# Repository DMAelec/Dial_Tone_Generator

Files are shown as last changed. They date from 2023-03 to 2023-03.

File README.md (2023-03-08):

# DIAL TONE GENERATOR

 This circuit provides a 1 volt peak-to-peak dial tone signal with equal proportions of 350Hz and 440Hz sine waves. The two frequencies are generated in multivibrator sections U1A and U1B. Triangle-like waveforms from the multivibrator sections are fed to summing amplifier U1D. A 470pF capacitor in the feedback path of U1D removes some of the unwanted harmonics from the composite waveform, which is then fed to section U1C, a Sallen-Key low-pass filter. U1C further reduces the harmonics, providing a high-quality summed-sine signal at its output. The two frequencies are close enough to permit a single-filter design, with the summing resistors at U1D's input selected to emphasize the 440Hz component, accordingly.

Calibration is performed by connecting a frequency counter to the "350 TP" and "440 TP" test points, and adjusting the respective trimmer potentiometers to obtain the correct frequencies. The frequencies are relatively independent of power supply voltage, and the single +7.5v power supply may be derived from a simple regulator circuit. The circuit consumes less than 3 milliamperes of current.

For convenience and economy, the circuit was designed with one CMOS quad op-amp integrated circuit.

BASED ON SCHEMATIC FROM:
https://www.theremin.us/Circuit_Library/dial_tone_generator.html

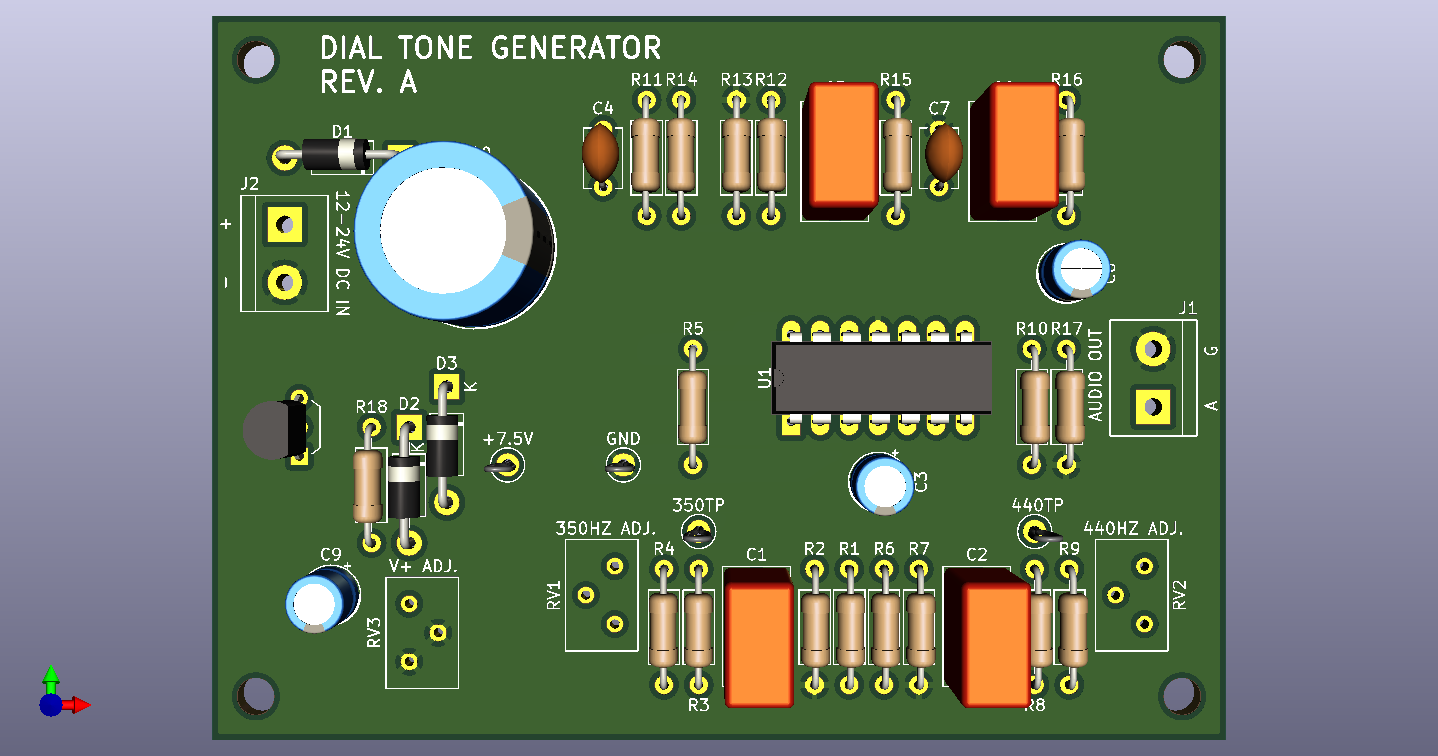
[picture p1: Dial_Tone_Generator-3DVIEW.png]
3DVIEW


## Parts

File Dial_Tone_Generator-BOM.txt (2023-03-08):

REFRENCE		|		DESCRIPTION		|		PART NUMBER
-------------------------------------------------------------------------------------------
C1, C2, C5, C6			0.1uF, ±5%, 50V				ECQ-E2104JFB
				RADIAL POLYESTER CAPACITOR 

C3, C8				1uF, ±10%, 20V				TAP105K020SCS
				RADIAL TANTALUM CAPACITOR

C4				470pF, ±5%, NPO, 100V			C320C471J1G5TA
				RADIAL CERAMIC CAPACITOR

C7				4700pF, ±5%, NPO, 100V			C320C472J1G5TA
				RADIAL CERAMIC CAPACITOR

C9				10uF, ±20%, 16V				ECA-1CM100I
				RADIAL ELECTROLYTIC CAPACITOR

C10				1000uF, ±20%, 35V			ECA-1VHG102
				RADIAL ELECTROLYTIC CAPACITOR

R1, R2, R6, R7			30.1K OHM, ±1%, 1/4W			MFR-25FBF52-30K1
				METAL FILM RESISTOR

R3, R8				178K OHM, ±1%, 1/4W			MFR-25FBF52-178K
				METAL FILM RESISTOR

R4				78.7K OHM, ±1%, 1/4W			MFR-25FBF52-78K7
				METAL FILM RESISTOR

R5, R11				1M OHM, ±5%, 1/4W			CFR-25JB-52-1M
				CARBON FILM RESISTOR

R9				61.9K OHM, ±1%, 1/4W			MFR-25FRF52-61K9
				METAL FILM RESISTOR

R10, R12, R13, R17		470K OHM, ±5%, 1/4W			CFR-25JB-52-470K
				CARBON FILM RESISTOR

R14				56K OHM, ±5%, 1/4W			CFR-25JB-52-56K
				CARBON FILM RESISTOR

R15				10K OHM, ±5%, 1/4W			CFR-25JB-52-10K
				CARBON FILM RESISTOR

R16				470 OHM, ±5%, 1/4W			CFR-25JB-52-470R
				CARBON FILM RESISTOR

R18				240 OHM, ±5%, 1/4W			CFR-25JB-52-240R
				CARBON FILM RESISTOR

RV1, RV2			10K OHM, 25 TURN			3299Y-1-103LF
				CERMET TRIMMER POTENTIOMETER

RV3				5K OHM, 25 TURN				3299Y-1-502LF
				CERMET TRIMMER POTENTIOMETER

D1, D2, D3			100V, 1A, DO-41				1N4002
				RECTIFIER DIODE

U1				QUAD OPERATIONAL AMPLIFIER		LMC6484IN/NOPB	
				INTEGRATED CIRCUIT

U2				ADJ LINEAR VOLTAGE REGULATOR		LM317LCLPR
				INTEGRATED CIRCUIT

J1, J2				5.08MM, 2 POSITION			TB007-508-02BE
				SCREW TERMINAL BLOCK

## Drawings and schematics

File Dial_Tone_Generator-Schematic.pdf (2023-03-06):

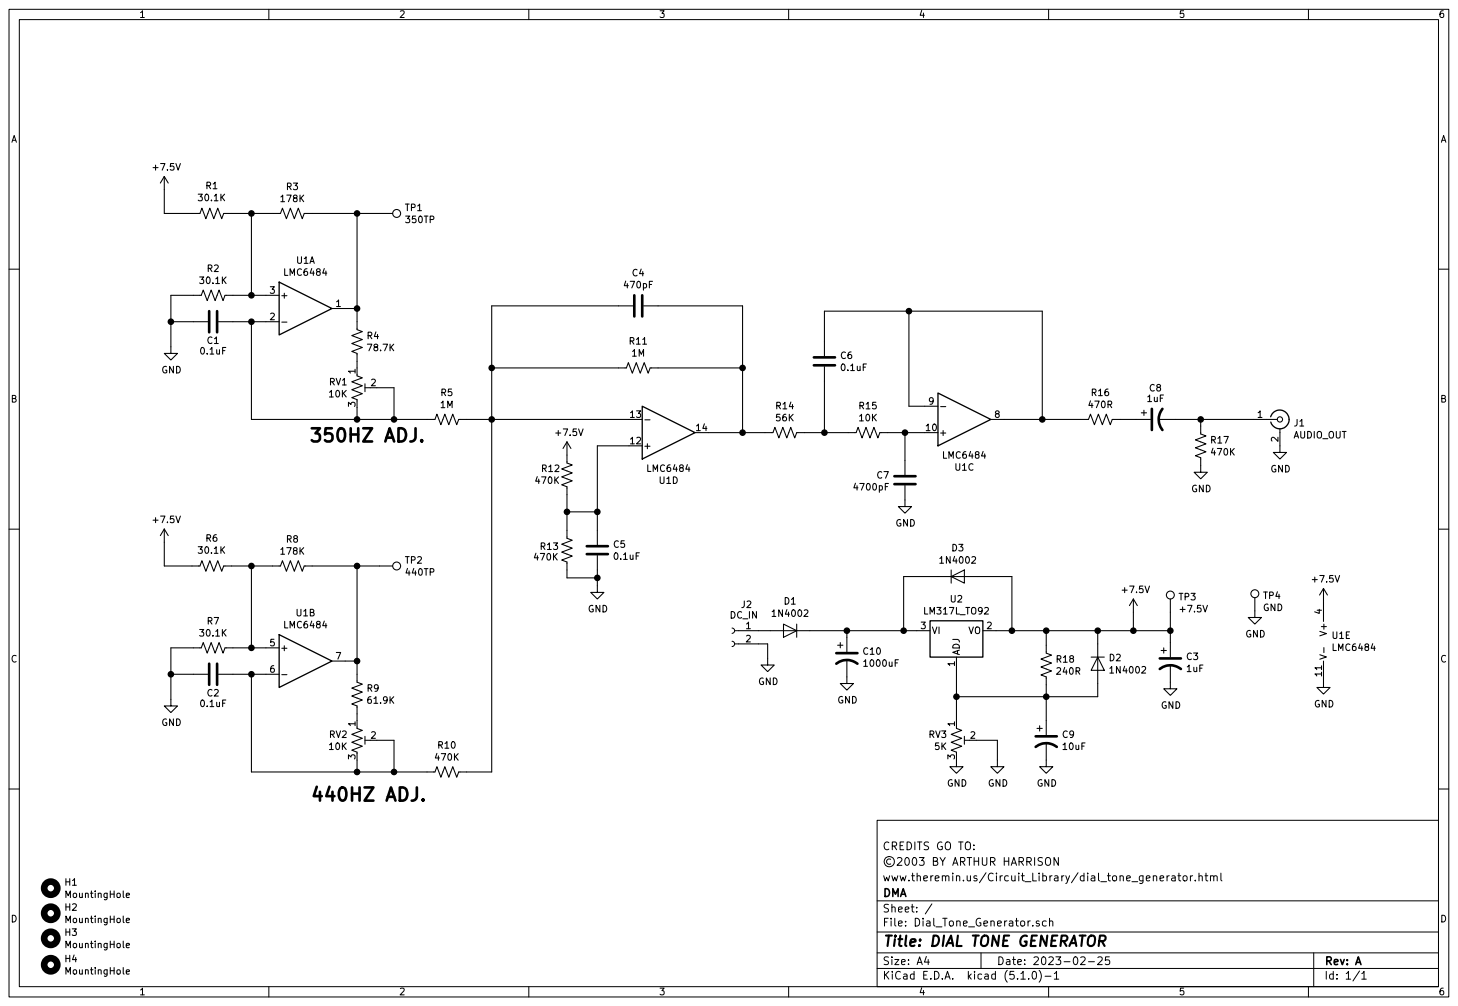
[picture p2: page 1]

CREDITS GO TO:
www.theremin.us/Circuit_Library/dial_tone_generator.html ©2003 BY ARTHUR HARRISON

File: Dial_Tone_Generator.sch Sheet: / DMA

Id: 1/1 Title: DIAL TONE GENERATOR

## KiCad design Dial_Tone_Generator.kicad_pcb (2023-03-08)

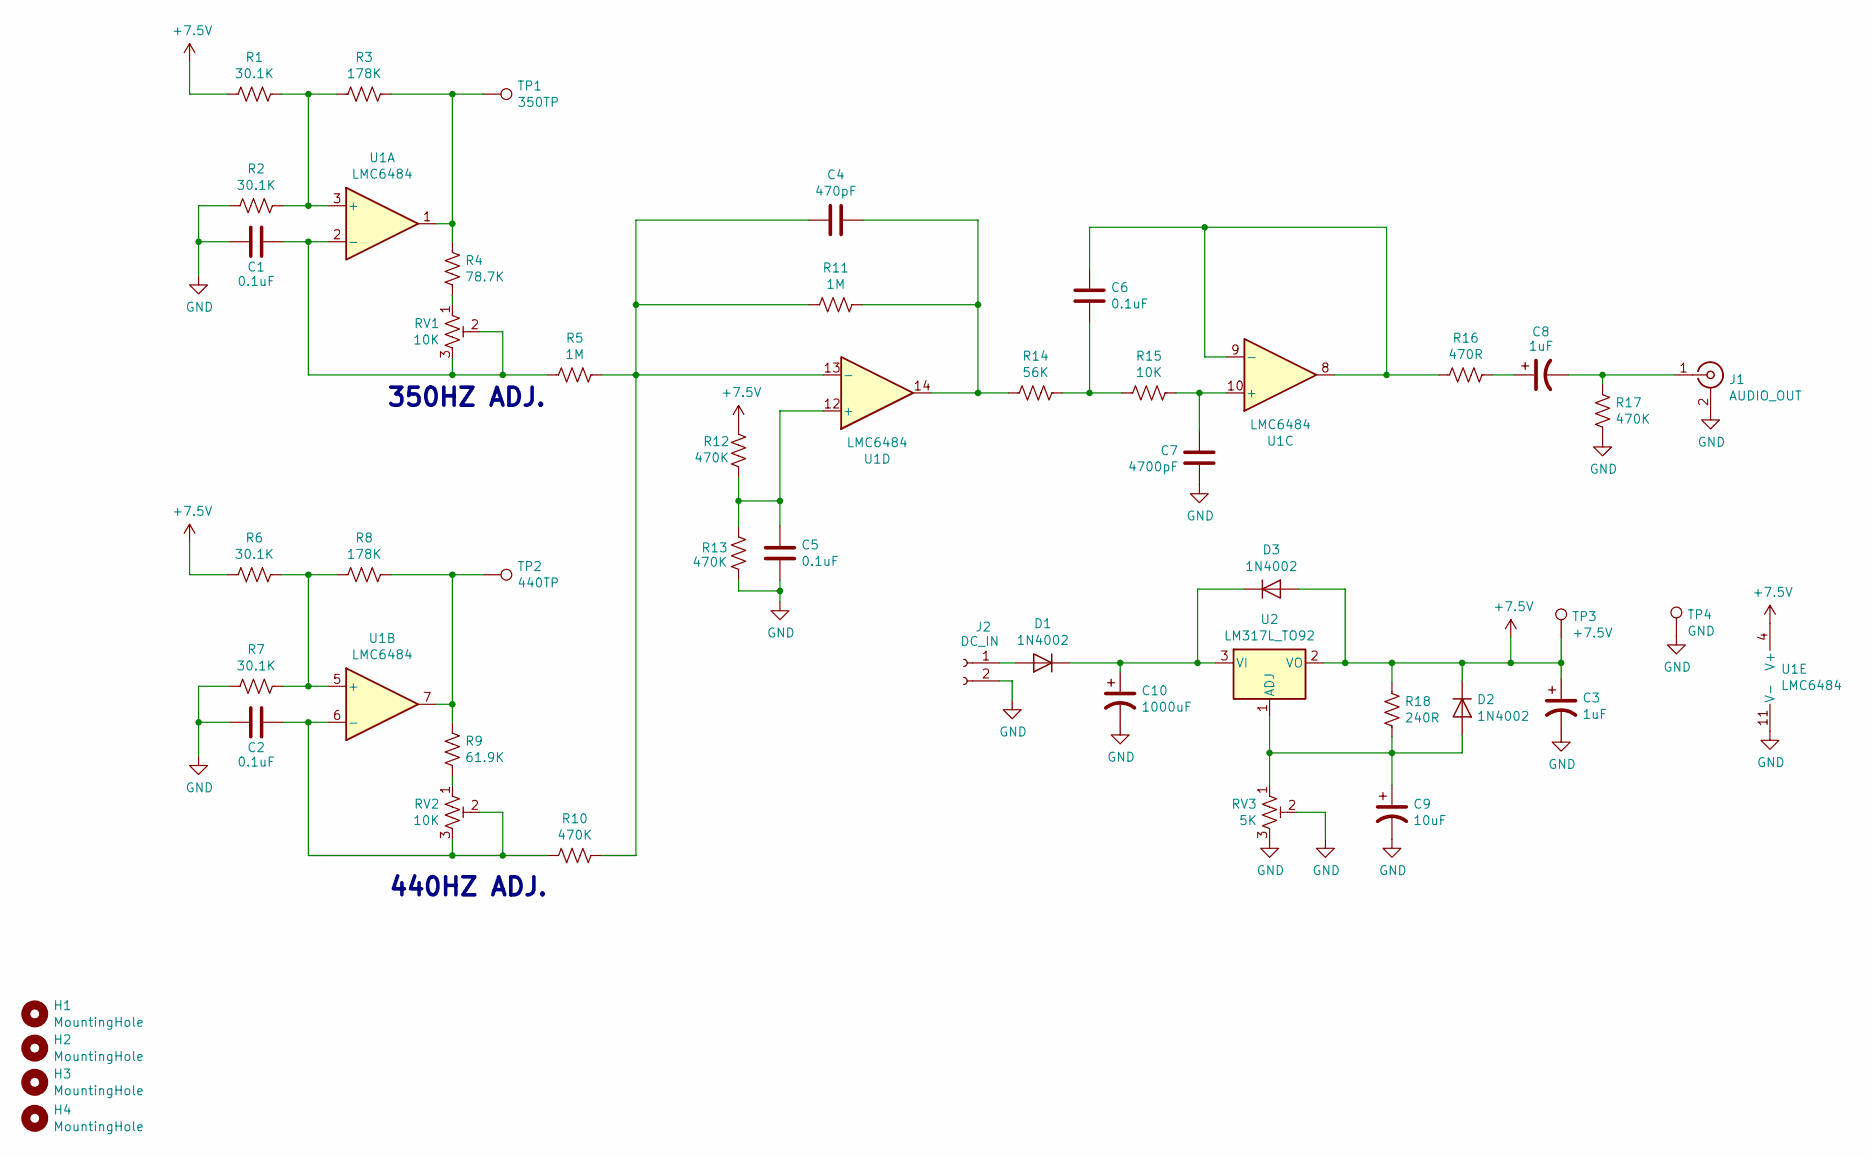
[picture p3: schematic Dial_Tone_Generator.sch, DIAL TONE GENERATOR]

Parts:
C1, C2, C5, C6: 0.1uF; C_Rect_L10.3mm_W5.7mm_P7.50mm_MKS4
C3, C8: 1uF; CP_Radial_D5.0mm_P2.50mm
C4: 470pF; C_Disc_D5.1mm_W3.2mm_P5.00mm
C7: 4700pF; C_Disc_D5.1mm_W3.2mm_P5.00mm
C9: 10uF; CP_Radial_D5.0mm_P2.50mm
C10: 1000uF; CP_Radial_D14.0mm_P5.00mm
D1, D2, D3: 1N4002; D_DO-41_SOD81_P10.16mm_Horizontal
H1, H2, H3, H4: MountingHole; MountingHole_3.2mm_M3
J1: AUDIO_OUT; TerminalBlock_bornier-2_P5.08mm
J2: DC_IN; TerminalBlock_bornier-2_P5.08mm
R1, R2, R6, R7: 30.1K; R_Axial_DIN0207_L6.3mm_D2.5mm_P10.16mm_Horizontal
R3, R8: 178K; R_Axial_DIN0207_L6.3mm_D2.5mm_P10.16mm_Horizontal
R4: 78.7K; R_Axial_DIN0207_L6.3mm_D2.5mm_P10.16mm_Horizontal
R5, R11: 1M; R_Axial_DIN0207_L6.3mm_D2.5mm_P10.16mm_Horizontal
R9: 61.9K; R_Axial_DIN0207_L6.3mm_D2.5mm_P10.16mm_Horizontal
R10, R12, R13, R17: 470K; R_Axial_DIN0207_L6.3mm_D2.5mm_P10.16mm_Horizontal
R14: 56K; R_Axial_DIN0207_L6.3mm_D2.5mm_P10.16mm_Horizontal
R15: 10K; R_Axial_DIN0207_L6.3mm_D2.5mm_P10.16mm_Horizontal
R16: 470R; R_Axial_DIN0207_L6.3mm_D2.5mm_P10.16mm_Horizontal
R18: 240R; R_Axial_DIN0207_L6.3mm_D2.5mm_P10.16mm_Horizontal
RV1, RV2: 10K; Potentiometer_Bourns_3299Y_Vertical
RV3: 5K; Potentiometer_Bourns_3299Y_Vertical
TP1: 350TP; TestPoint_Loop_D2.50mm_Drill1.0mm
TP2: 440TP; TestPoint_Loop_D2.50mm_Drill1.0mm
TP3: +7.5V; TestPoint_Loop_D2.50mm_Drill1.0mm
TP4: GND; TestPoint_Loop_D2.50mm_Drill1.0mm
U1: LMC6484; DIP-14_W7.62mm_LongPads
U2: LM317L_TO92; TO-92_Inline_Wide

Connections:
+7.5V: C3.1, D2.1 (K), D3.2 (A), R1.1, R6.1, R12.1, R18.1, TP3.1, U1.4 (V+), U2.2 (VO)
GND: C1.2, C2.2, C3.2, C5.2, C7.2, C9.2, C10.2, J1.2 (Ext), J2.2, R2.2, R7.2, R13.2, R17.2, RV3.2, RV3.3, TP4.1, U1.11 (V-)
unnamed: C1.1, R5.2, RV1.2, RV1.3, U1.2 (-)
unnamed: C2.1, R10.2, RV2.2, RV2.3, U1.6 (-)
unnamed: C4.1, R11.1, R14.2, U1.14
unnamed: C4.2, R5.1, R10.1, R11.2, U1.13 (-)
unnamed: C5.1, R12.2, R13.1, U1.12 (+)
unnamed: C6.1, R16.2, U1.8, U1.9 (-)
unnamed: C6.2, R14.1, R15.2
unnamed: C7.1, R15.1, U1.10 (+)
unnamed: C8.1, R16.1
unnamed: C8.2, J1.1 (In), R17.1
unnamed: C9.1, D2.2 (A), R18.2, RV3.1, U2.1 (ADJ)
unnamed: C10.1, D1.1 (K), D3.1 (K), U2.3 (VI)
unnamed: D1.2 (A), J2.1
unnamed: R1.2, R2.1, R3.2, U1.3 (+)
unnamed: R3.1, R4.1, TP1.1, U1.1
unnamed: R4.2, RV1.1
unnamed: R6.2, R7.1, R8.2, U1.5 (+)
unnamed: R8.1, R9.1, TP2.1, U1.7
unnamed: R9.2, RV2.1

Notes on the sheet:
440HZ ADJ.
350HZ ADJ.

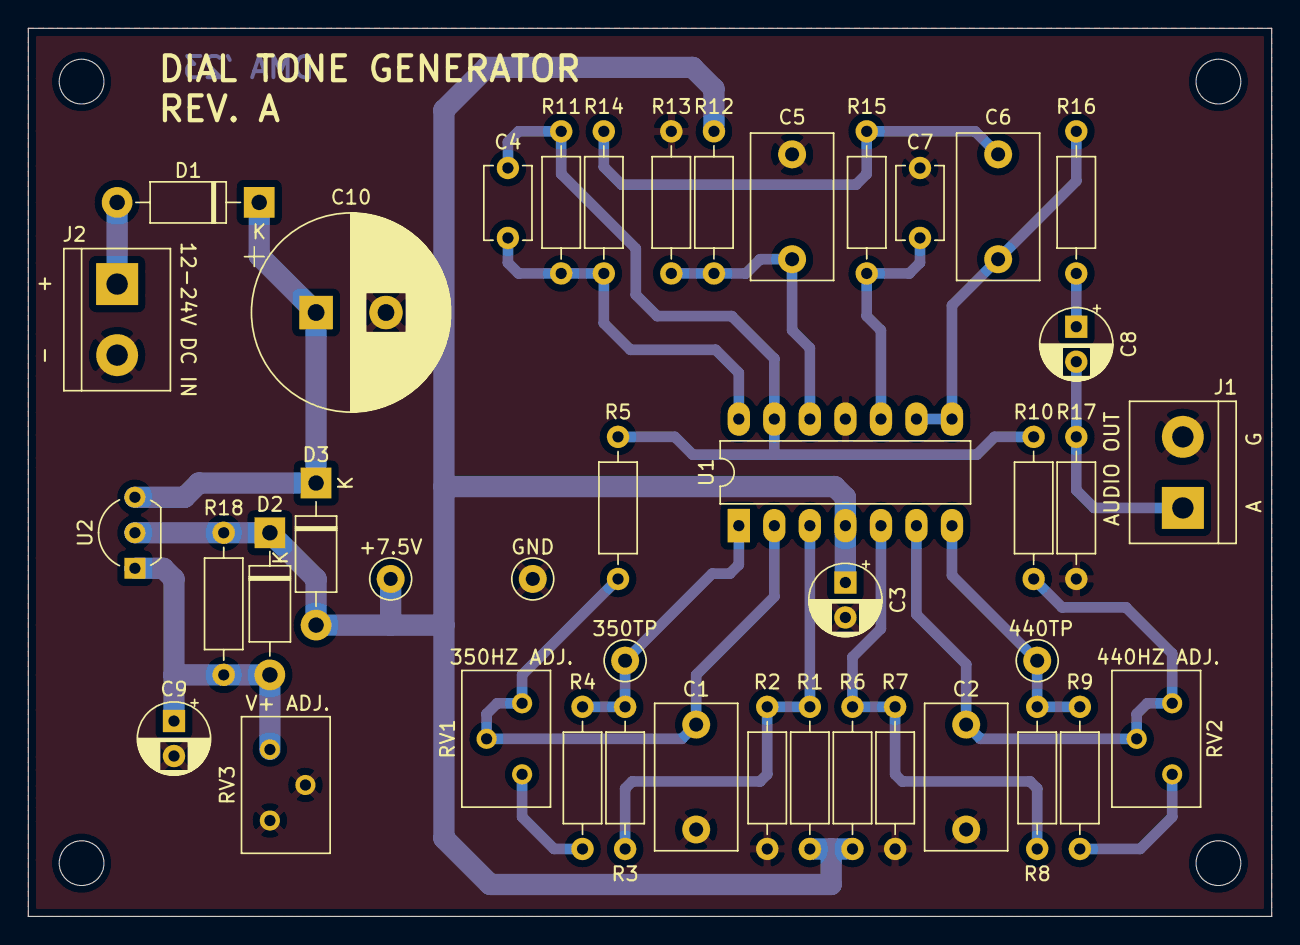
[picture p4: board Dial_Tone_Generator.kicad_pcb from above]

Board: 2 copper layers, 88.9 x 63.5 mm, 46 parts (0 on the bottom side), 21 nets.

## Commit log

2023-03-06 some schematic changes
    [Dial_Tone_Generator.sch]
2023-03-07 Some PCB cleanup
    [Dial_Tone_Generator.kicad_pcb]
2023-03-08 generated gerber files
    [Dial_Tone_Generator.kicad_pcb]
2023-03-08 updated BOM
